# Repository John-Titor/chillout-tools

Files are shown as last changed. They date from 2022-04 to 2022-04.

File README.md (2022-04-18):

# chillout-tools
reomote protocol tools etc. for the Chillout Systems family of personal cooling systems

# decoder.py
simple serial protocol decoder for the remote <-> compressor protocol

# AnalogInterface
Firmware, schematic and PCB for an adapter that allows the use of a Chillout Quantum V3 (and probably others with minor changes) with a CoolShirt controller.

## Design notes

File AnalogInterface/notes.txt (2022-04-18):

LPC 810 pin map for Chillout controller
---------------------------------------

mandatory
---------
serial rx
serial tx
tx enable
pwm in

optional
--------
reset
LED driver
debug

Coolshirt dual controller knob position : PWM duty cycle
--------------------------------------------------------

0: 1.5%
1/4: 35%
1/2: 75%
3/4: 90%
1: 100%

approximate curve fit (quadratic regression):
	y = -0.8285714 + 1.846286*x - 0.008342857*x^2

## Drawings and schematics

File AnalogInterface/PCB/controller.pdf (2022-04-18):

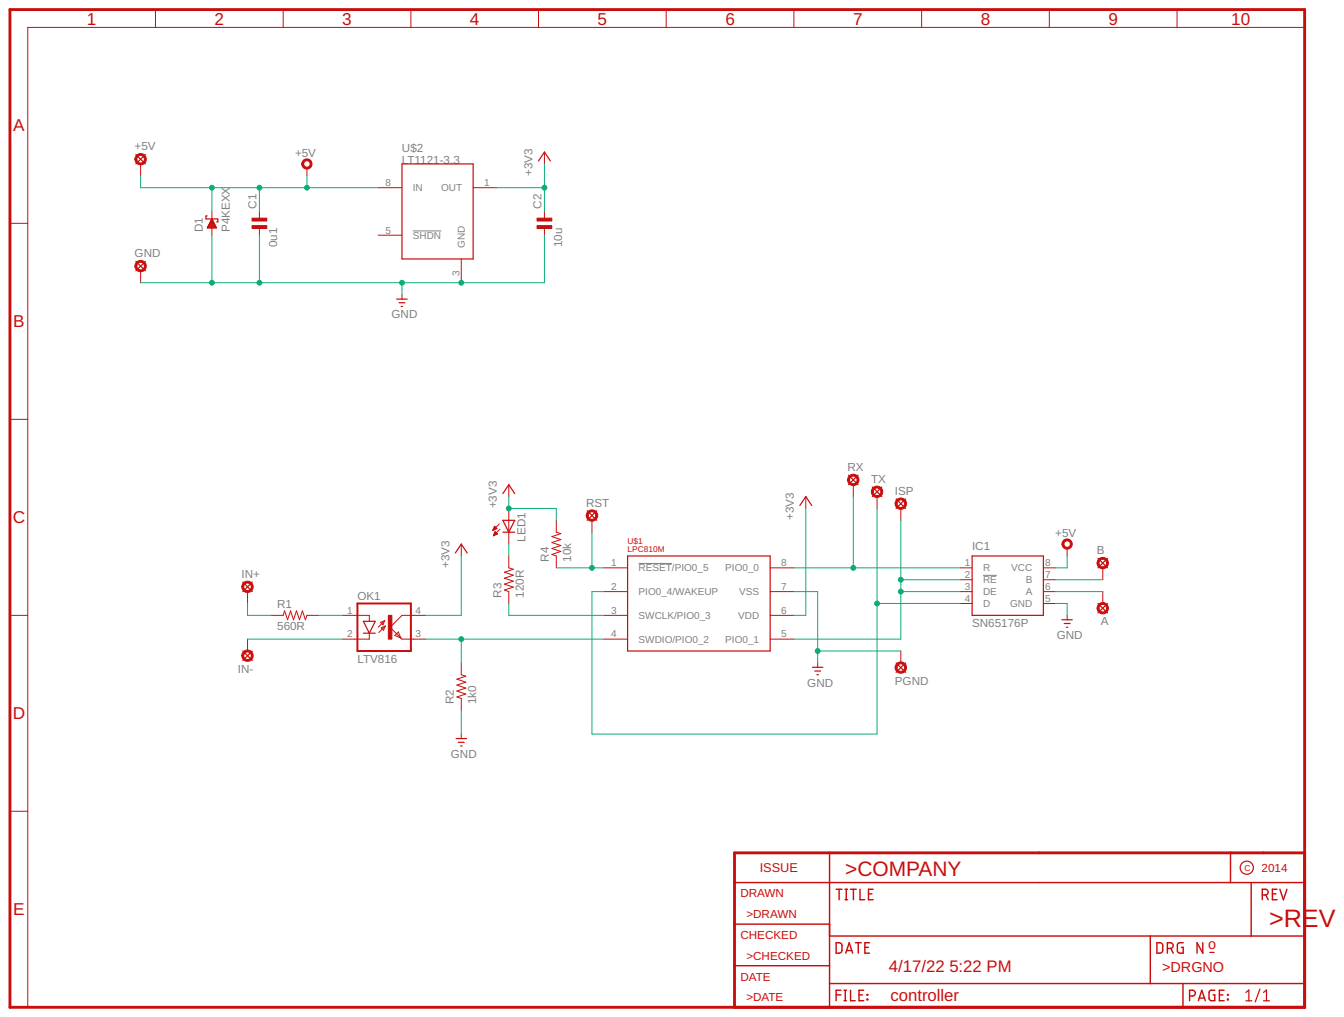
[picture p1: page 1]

>COMPANY

>DRAWN

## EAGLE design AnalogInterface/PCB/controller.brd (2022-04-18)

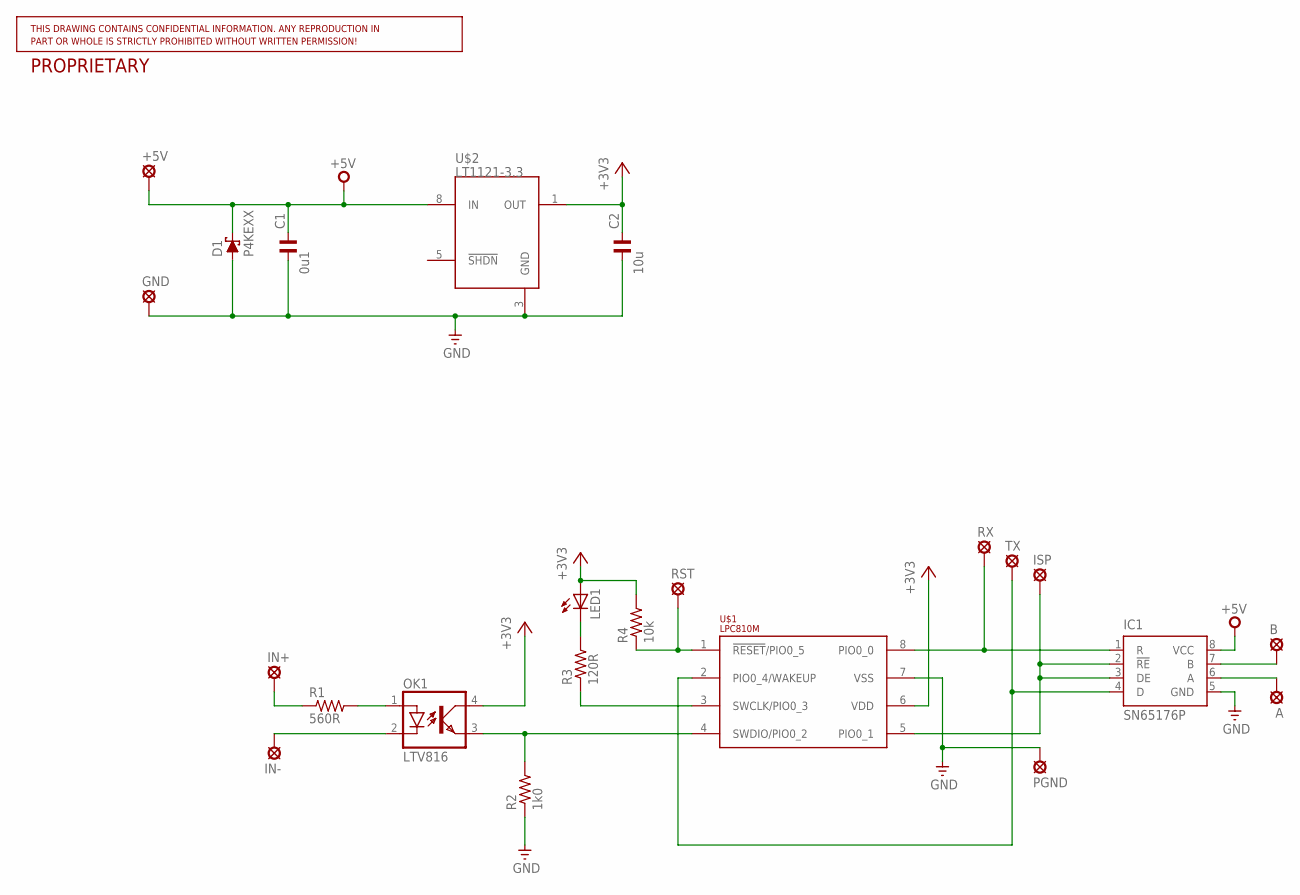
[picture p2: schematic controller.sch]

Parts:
+5V: SE14
A: SE14
B: SE14
C1: 0u1; C050-024X044
C2: 10u; C050-024X044
D1: P4KEXX; DO41-10
GND: SE14
IC1: SN65176P; DIL08
IN+: SE14
IN-: SE14
ISP: SE14
LED1: LED-3MM-NO_SILK; LED3MM-NS
OK1: LTV816; DIL04
PGND: SE14
R1: 560R; 0207/10B
R2: 1k0; 0207/10B
R3: 120R; 0207/10B
R4: 10k; 0207/10B
RST: SE14
RX: SE14
TX: SE14
U$1: LPC810M; DIL08
U$2: LT1121-3.3; DIL08

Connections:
+3V3: C2.1, LED1.A, OK1.4 (COL), R4.2, U$1.6 (VDD), U$2.1 (OUT)
+5V: +5V.MP, C1.1, D1.C, IC1.8 (VCC), U$2.8 (IN)
GND: C1.2, C2.2, D1.A, GND.MP, IC1.5 (GND), PGND.MP, R2.1, U$1.7 (VSS), U$2.3 (GND)
unnamed: IC1.1 (R), RX.MP, U$1.8 (PIO0_0)
unnamed: IN+.MP, R1.1
unnamed: OK1.1 (A), R1.2
unnamed: IN-.MP, OK1.2 (C)
unnamed: OK1.3 (EMIT), R2.2, U$1.4 (SWDIO/PIO0_2)
unnamed: IC1.4 (D), TX.MP, U$1.2 (PIO0_4/WAKEUP)
unnamed: IC1.2 (!RE), IC1.3 (DE), ISP.MP, U$1.5 (PIO0_1)
unnamed: LED1.K (C), R3.2
unnamed: B.MP, IC1.7 (B)
unnamed: A.MP, IC1.6 (A)
unnamed: R3.1, U$1.3 (SWCLK/PIO0_3)
unnamed: R4.1, RST.MP, U$1.1 (!RESET!/PIO0_5)

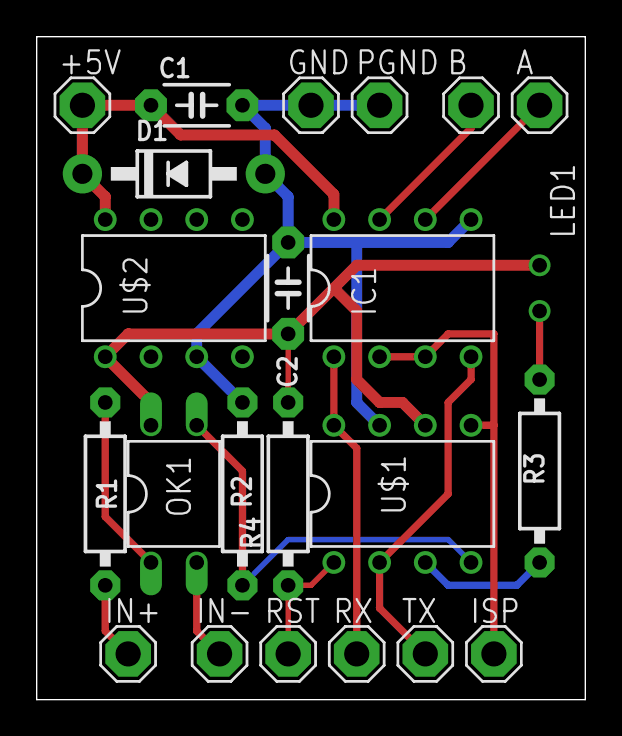
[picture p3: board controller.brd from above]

Board: 2 copper layers, 30.5 x 36.8 mm, 23 parts (0 on the bottom side), 15 nets.

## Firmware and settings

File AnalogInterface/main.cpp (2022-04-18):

// Copyright (c) 2022 Michael Smith, All Rights Reserved
//
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
//  o Redistributions of source code must retain the above copyright
//    notice, this list of conditions and the following disclaimer.
//  o Redistributions in binary form must reproduce the above copyright
//    notice, this list of conditions and the following disclaimer in
//    the documentation and/or other materials provided with the distribution.
//
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

// Overview
// ========
//
// Sample the ~40Hz PWM signal generated by the Cool Shirt pump controller
// and command a Chillout Quantum V3 compressor accordingly. Other compressor
// models are likely similar, but this is the one we need to talk to.
//
// The controller generates a very low duty cycle (~1%) at minimum setting,
// so it is possible to distinguish between "off" and "minimum".
//
// System configuration:
// =====================
//
// Core/AHB clock: 24MHz
// UART: RS-485
// Timer0: input poll @ 1kHz
// Timer1: inline delays
// Timer2: LED flash
// Timer3: receive timeout
//

#define RXD     P0_0    // RS-485 receive
#define TXD     P0_4    // RS-485 send
#define RXTX    P0_1    // RS-485 transciever control: low = receive, high = send
#define IN      P0_2    // Input current sensor: low = no current, high = current
#define LED     P0_3    // LED: low = on, high = off

#include <sysctl.h>
#include <pin.h>
#include <timer.h>
#include <sct.h>
#include <interrupt.h>

#include "input.h"
#include "chillout.h"
#include "rs485.h"
#include "statusled.h"

extern "C" int main();

void
sample_tick()
{
   Input::sample(IN);
}

void
led_tick()
{
    StatusLED::tick(LED);
}

int
main()
{
    Sysctl::init_24MHz();

    // Make reset pin work for easier in-system flashing.
    RST.enable();

    // Setup input pin
    IN.configure(Pin::Input, Pin::PullDown);

    // Serial interface up.
    RS485::init();

    // 1ms timer callback to sample input.
    Timer0.configure(sample_tick, MSEC(1), Timer::periodic);

    // Turn on the LED
    LED.configure(Pin::Output, Pin::PushPull).set(0);

    // 250ms LED timer tick
    Timer2.configure(led_tick, MSEC(125), Timer::periodic);

    // main loop
    for (;;) {
        unsigned c;

        // Poll for status packet bytes; once a packet has been completely received
        // use the idle window to possibly send an update to adjust the compressor
        // settings.
        //
        if (RS485::recv(c)) {
            if (Chillout::recv(c)) {

                // compressor needs update to match input?
                RS485::send(Chillout::update_command(Input::target()));

                // update LED
                if (Chillout::mode & Chillout::MODE_ON) {
                    StatusLED::mode = StatusLED::ON;
                } else {
                    StatusLED::mode = StatusLED::OFF;
                }

                // reset comms timeout timer
                Timer3.configure(MSEC(2000));
            }
        }

        // Check for comms timeout
        if (Timer3.expired()) {
            StatusLED::mode = StatusLED::ERROR;
        }
    }
}

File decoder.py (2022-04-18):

#!/usr/bin/env python3
#
# Chillout Quantum v3 protocol analyser
#
# Interface is RS-485 @ 115200n81. Other units (pro, etc.) look to use a similar
# protocol at 9600n81 but not yet verified / supported here.
#
# Circular connector pinout at the compressor unit (pin numbers are marked on the
# remote cable connector face):
#
#  1: +5V
#  2: RS-485 A
#  3: RS-485 B
#  4: GND
#
# Packet format:
# =============
#
# Example: c00e0100080002078e000200008401
#            LLAAPPPPPPPPPPPPPPPPPPPPSS
#
# LL is packet length -1
# AA is sender address, 1, 2 = compressor, 3 = remote
# PP is packet data
# SS is CRC-8 with final Xor of PP bytes based on AA value; 1 = 0x30, 2 = 0xea, 3 = 0xe9
#
#
# Remote packet data:
# ==================
#
# PPxxTTMM
#
# PP is power mode; 0x00 = off, 0x01 = eco, 0x03 = max
# TT is set temperature, 1 = min (1.7°C, units seem to be ~2.7°C) 10 = max
# MM is 0x00 when changing PP, 0x01 when changing TT
#
#
# Compressor packet data:
# ======================
#
# multi-byte fields are big-endian
#
# PPxxxxTTCCCCxxxxRRRR
#
# PP is power mode (see remote)
# TT is set temperature (see remote)
# CCCC is coolant temperature in 1/100°C
# RRRR is compressor speed in rpm.
#

import serial
import crccheck
import struct

#ser = serial.Serial('/dev/cu.usbserial-A106TL0J', 115200)
ser = serial.Serial('/dev/cu.SLAB_USBtoUART', 115200)
crc_alg = {
    1: crccheck.crc.Crc(width=8,
                        poly=0x07,
                        initvalue=0x00,
                        reflect_input=False,
                        reflect_output=False,
                        xor_output=0x30,
                        check_result=0xf4),
    2: crccheck.crc.Crc(width=8,
                        poly=0x07,
                        initvalue=0x00,
                        reflect_input=False,
                        reflect_output=False,
                        xor_output=0xea,
                        check_result=0xf4),
    3: crccheck.crc.Crc(width=8,
                        poly=0x07,
                        initvalue=0x00,
                        reflect_input=False,
                        reflect_output=False,
                        xor_output=0xe9,
                        check_result=0xf4),
    }

power_modes = ['off', 'eco', 'off', 'max']
set_temps = [0, 1.3, 4.4, 7.2, 10.0, 12.7, 15.5, 18.3, 21.1, 23.9, 26.7]

while True:
    hdr = ser.read(1)
    if hdr != b'\xc0':
        print(f'skip {hdr.hex()}')
        continue
    pktlen = ord(ser.read(1))
    if pktlen < 5:
        print(f'!len {pktlen.hex()}')
        continue
    addr = ord(ser.read(1))
    data = ser.read(pktlen - 4)
    check = ord(ser.read(1))
    f = ser.read(1)
    if f != b'\x01':
        print(f'!frame2 {f.hex()}')
        continue
    try:
        computed_check = crc_alg[addr].calc(data)
        if check != computed_check:
            print(f'!CRC got {check:#x}')
    except KeyError:
        print(f'!addr {addr}')
    print(f'{addr}:{data.hex()}')

    if addr == 1:
        mode, _, _, set_temp, coolant_temp, _, _, rpm = struct.unpack('>BBBBHBBH', data)
        print(f'mode {power_modes[mode]}  set {set_temps[set_temp]}°C  coolant {coolant_temp / 100}°C  compressor {rpm}rpm')

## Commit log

2022-04-18 Add CoolShirt analog controller interface
    [controller.brd, controller.sch]
2022-04-18 add schematic PDF, remove confidentiality notice
    [controller.sch]
